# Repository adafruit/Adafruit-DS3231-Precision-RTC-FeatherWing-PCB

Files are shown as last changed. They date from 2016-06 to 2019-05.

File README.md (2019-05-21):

## DS3231 Precision RTC FeatherWing - RTC Add-on PCB
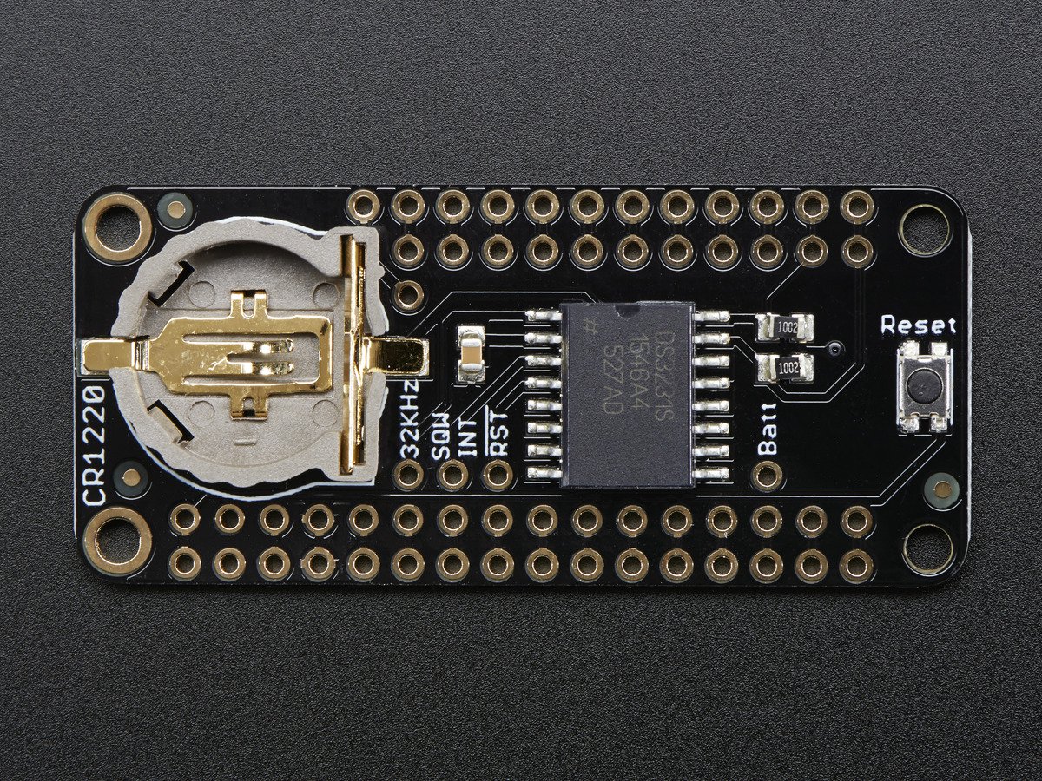
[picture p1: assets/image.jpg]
<a href="http://www.adafruit.com/products/3028"><br/>
Click here to purchase one from the Adafruit shop</a>

A Feather board without ambition is a Feather board without FeatherWings! This is the DS3231 Precision RTC FeatherWing: it adds an extremely accurate I2C-integrated Real Time Clock (RTC) with a Temperature Compensated Crystal Oscillator (TCXO)  to any Feather main board. This RTC is the most precise you can get in a small, low power package. Using our Feather Stacking Headers or Feather Female Headers you can connect a FeatherWing on top of your Feather board and let the board take flight!

Most RTCs use an external 32kHz timing crystal that is used to keep time with low current draw. And that's all well and good, but those crystals have slight drift, particularly when the temperature changes (the temperature changes the oscillation frequency very very very slightly but it does add up!) This RTC is in a beefy package because the crystal is inside the chip! And right next to the integrated crystal is a temperature sensor. That sensor compensates for the frequency changes by adding or removing clock ticks so that the timekeeping stays on schedule.

PCB files for the DS3231 Precision RTC FeatherWing. The format is EagleCAD schematic and board layout
- https://www.adafruit.com/products/3028

### License

Adafruit invests time and resources providing this open source design, please support Adafruit and open-source hardware by purchasing products from [Adafruit](https://www.adafruit.com)!

All text above must be included in any redistribution

Designed by Limor Fried/Ladyada for Adafruit Industries.
Creative Commons Attribution/Share-Alike, all text above must be included in any redistribution. 
See license.txt for additional information.

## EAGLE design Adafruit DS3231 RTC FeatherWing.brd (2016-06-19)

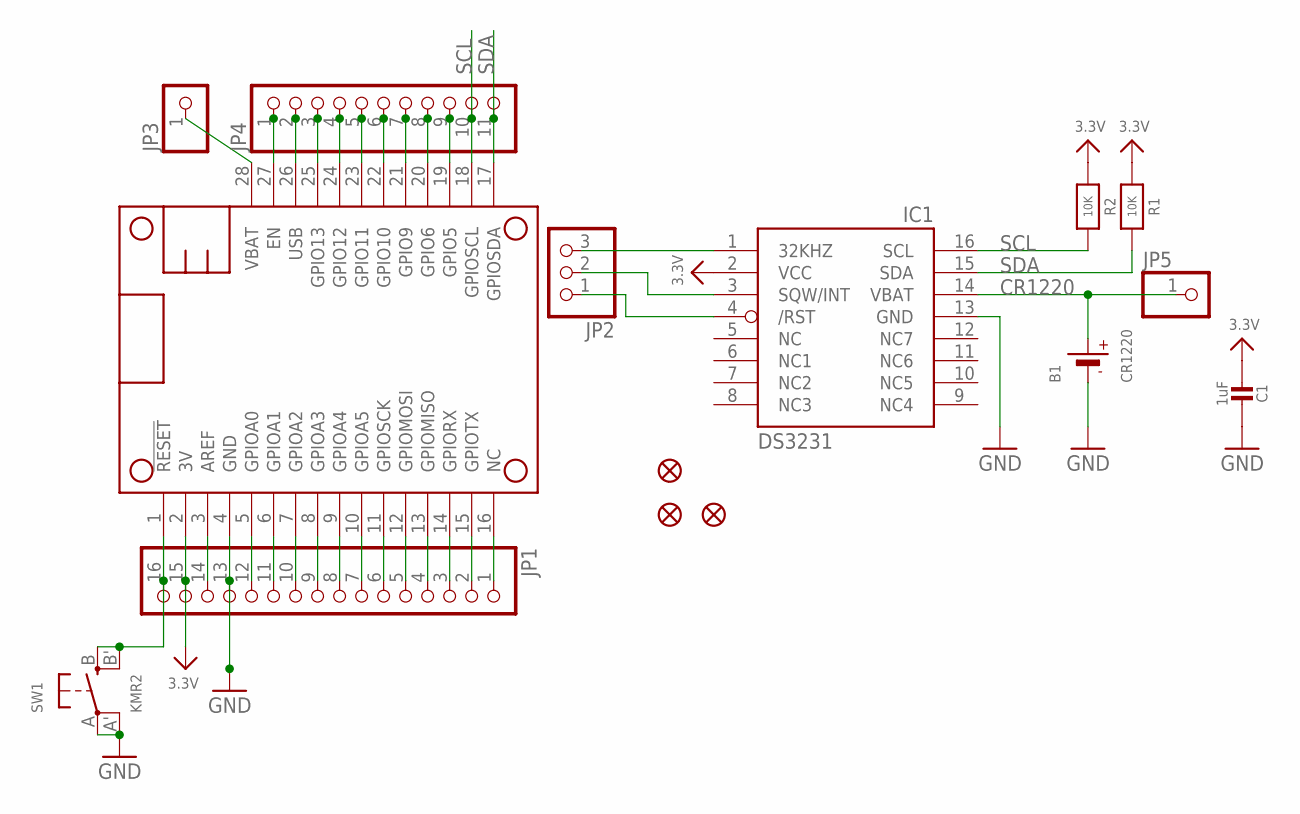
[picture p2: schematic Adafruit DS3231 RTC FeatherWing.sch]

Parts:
B1: CR1220; CR1220-2
C1: 1uF; 0805-NO
FID1, FID2, FID3: FIDUCIAL""; FIDUCIAL_1MM
IC1: DS3231/SO; SO16W
JP1: HEADER-1X16ROUND; 1X16_ROUND
JP2: HEADER-1X3ROUND; 1X03_ROUND
JP3, JP5: HEADER-1X1ROUND; 1X01_ROUND
JP4: HEADER-1X11; 1X11_ROUND
MS1: MICROSHIELD_NODIM; MICROSHIELD_DIM
R1, R2: 10K; 0805-NO
SW1: KMR2; BTN_KMR2_4.6X2.8

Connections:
3.3V: C1.2, IC1.2 (VCC), JP1.15, MS1.2 (3V), R1.1, R2.1
32KHZ: IC1.1 (32KHZ), JP2.3
!RTC_RST: IC1.4 (/RST), JP2.1
CR1220: B1.+, IC1.14 (VBAT), JP5.1
GND: B1.-, C1.1, IC1.13 (GND), JP1.13, MS1.4 (GND), SW1.A, SW1.A' (P1)
unnamed: JP1.1, MS1.16 (NC)
unnamed: JP1.2, MS1.15 (GPIOTX)
unnamed: JP1.3, MS1.14 (GPIORX)
unnamed: JP1.4, MS1.13 (GPIOMISO)
unnamed: JP1.5, MS1.12 (GPIOMOSI)
unnamed: JP1.6, MS1.11 (GPIOSCK)
unnamed: JP1.7, MS1.10 (GPIOA5)
unnamed: JP1.8, MS1.9 (GPIOA4)
unnamed: JP1.9, MS1.8 (GPIOA3)
unnamed: JP1.10, MS1.7 (GPIOA2)
unnamed: JP1.11, MS1.6 (GPIOA1)
unnamed: JP1.12, MS1.5 (GPIOA0)
unnamed: JP4.1, MS1.27 (EN)
unnamed: JP4.3, MS1.25 (GPIO13)
unnamed: JP4.4, MS1.24 (GPIO12)
unnamed: JP4.5, MS1.23 (GPIO11)
unnamed: JP4.6, MS1.22 (GPIO10)
unnamed: JP4.7, MS1.21 (GPIO9)
unnamed: JP4.8, MS1.20 (GPIO6)
unnamed: JP4.9, MS1.19 (GPIO5)
unnamed: JP1.14, MS1.3 (AREF)
unnamed: JP1.16, MS1.1 (!RESET), SW1.B (S), SW1.B' (S1)
SCL: IC1.16 (SCL), JP4.10, MS1.18 (GPIOSCL), R2.2
SDA: IC1.15 (SDA), JP4.11, MS1.17 (GPIOSDA), R1.2
SQW: IC1.3 (SQW/INT), JP2.2
USB: JP4.2, MS1.26 (USB)
VBAT: JP3.1, MS1.28 (VBAT)

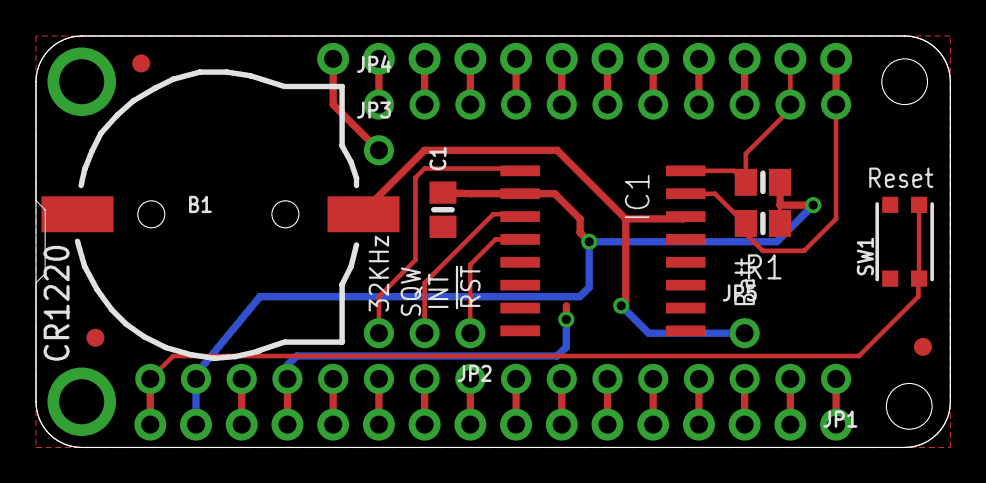
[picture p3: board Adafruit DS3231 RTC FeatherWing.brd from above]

Board: 2 copper layers, 50.8 x 22.9 mm, 16 parts (1 on the bottom side), 32 nets.

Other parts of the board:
U$6: FEATHERLOGO

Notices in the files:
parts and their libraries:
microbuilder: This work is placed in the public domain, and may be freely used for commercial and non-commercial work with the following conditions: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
